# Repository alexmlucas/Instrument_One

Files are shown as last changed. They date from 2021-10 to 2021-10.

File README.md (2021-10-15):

# Instrument_One
A guitar-inspired accessible musical instrument

Instrument One was designed in collaboration with physically disabled musician Eoin Fitzpatrick, his father Peter and the Drake Music Project Northern Ireland. It is a novel, guitar-inspired accessible instrument that recreates the experience of selecting chords on a fretboard and strumming guitar strings. It is a novel instrument, tailored towards Eoin's unique requirements.

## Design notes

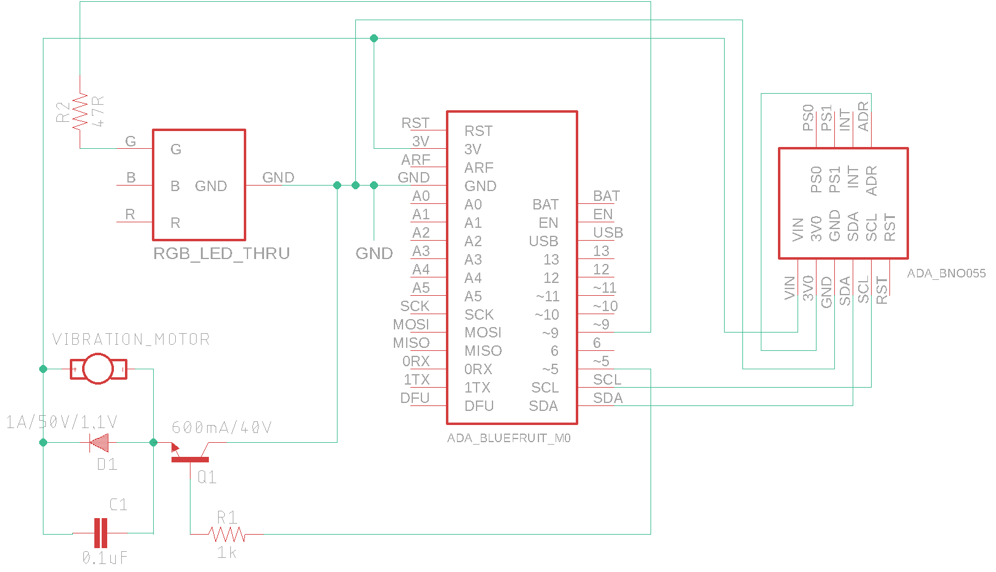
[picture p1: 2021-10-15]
electronics/wristband_schematic.png

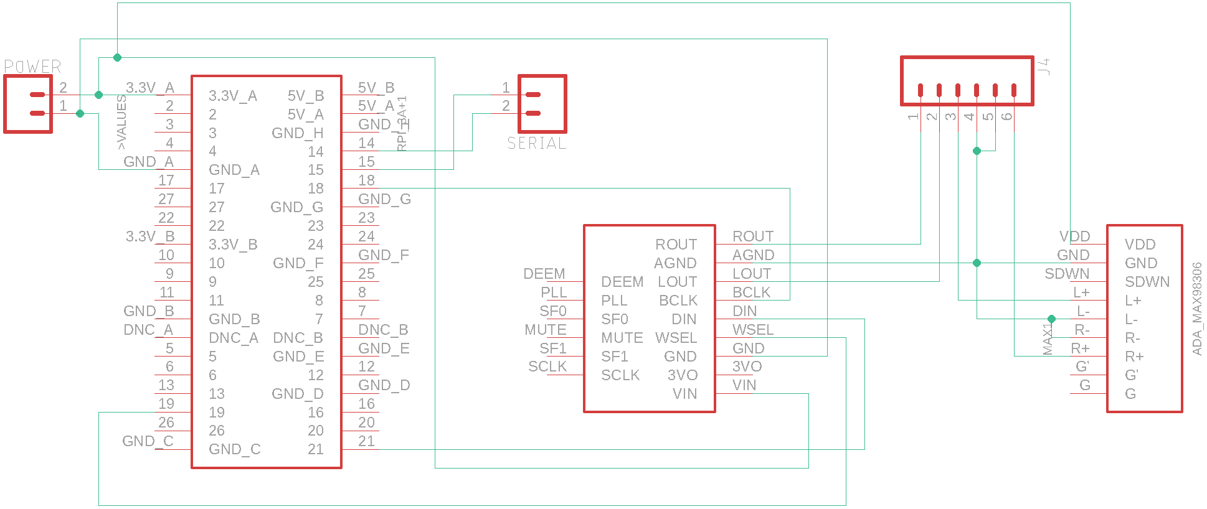
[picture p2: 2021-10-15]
electronics/audio_hat_schematic.png

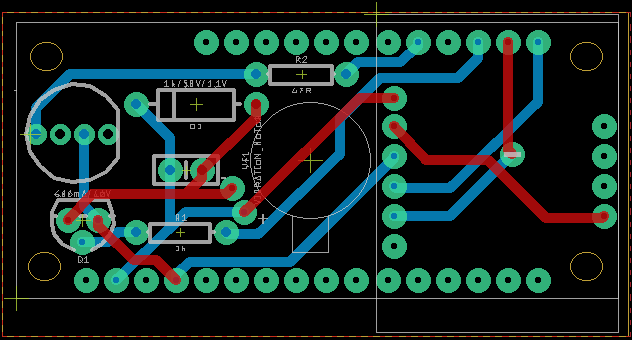
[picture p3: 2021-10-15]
electronics/wristband_board_layout.png

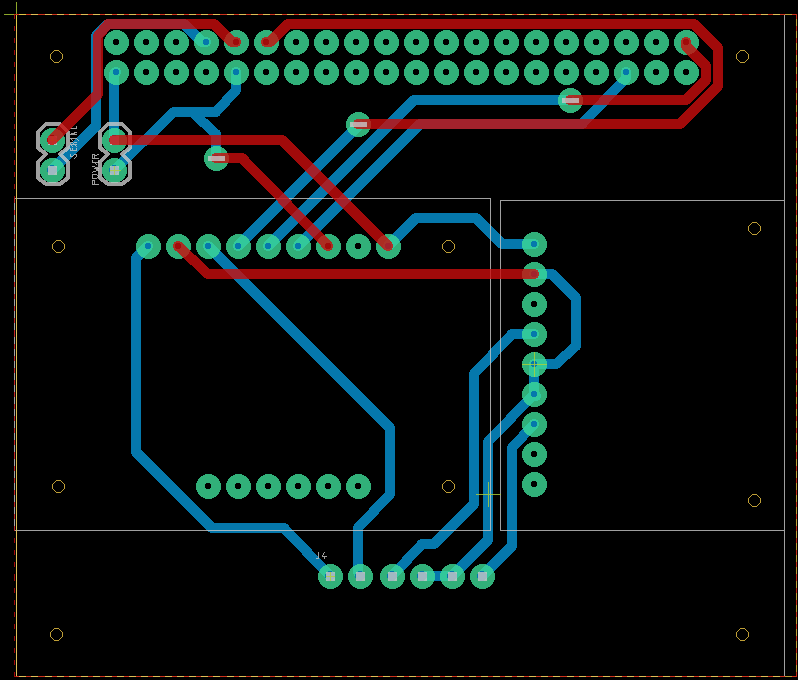
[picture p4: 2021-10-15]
electronics/audio_hat_board_layout.png

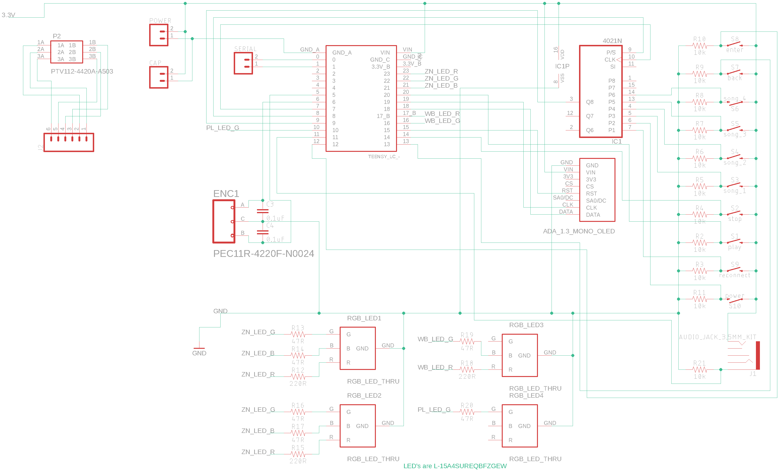
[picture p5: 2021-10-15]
electronics/control_board_schematic.png

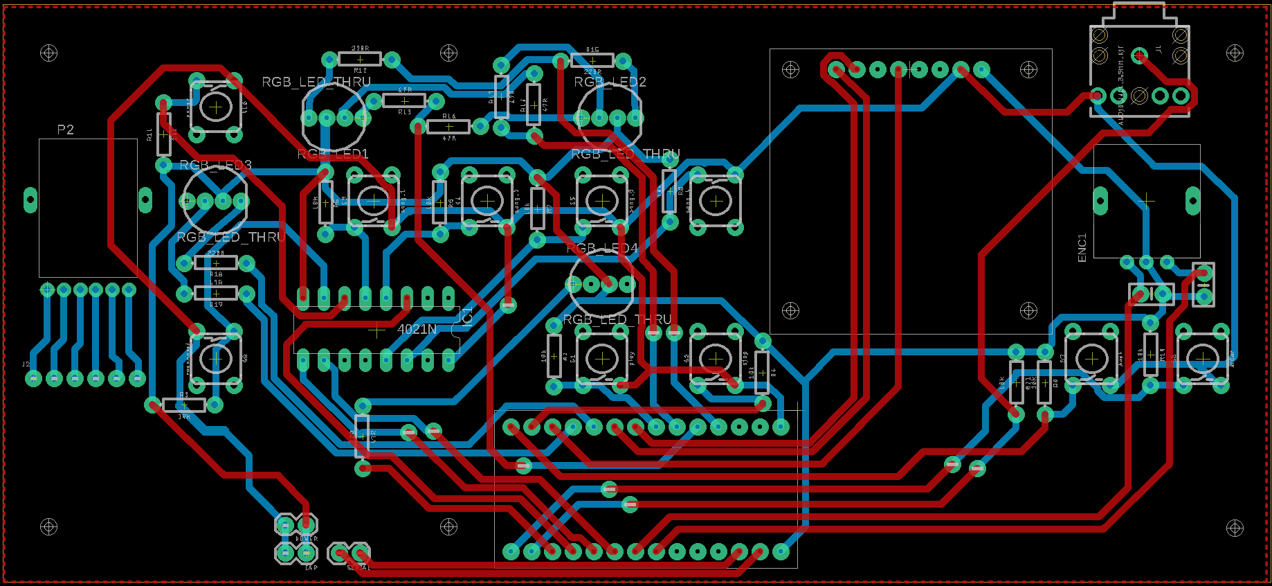
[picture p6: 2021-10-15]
electronics/control_board_layout.png

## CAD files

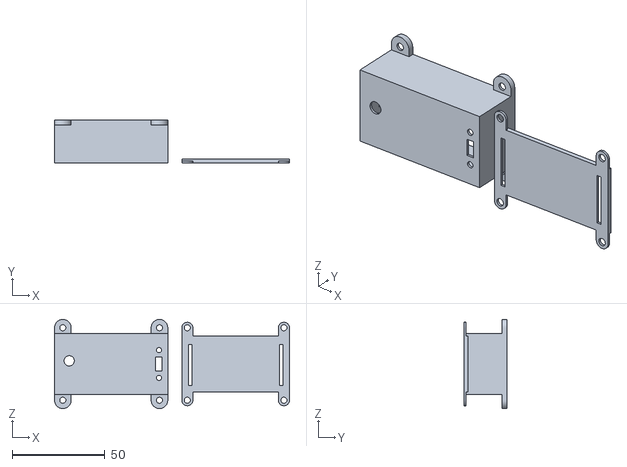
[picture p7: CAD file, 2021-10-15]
hardware/wristband_enclosure.stl
126.5 x 23.0 x 48.0

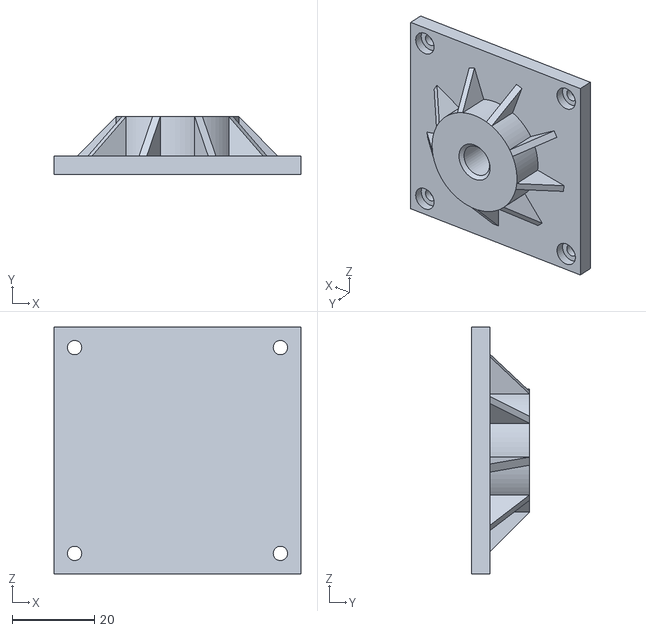
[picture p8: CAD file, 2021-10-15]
hardware/camera_mount.stl
60.0 x 14.0 x 60.0

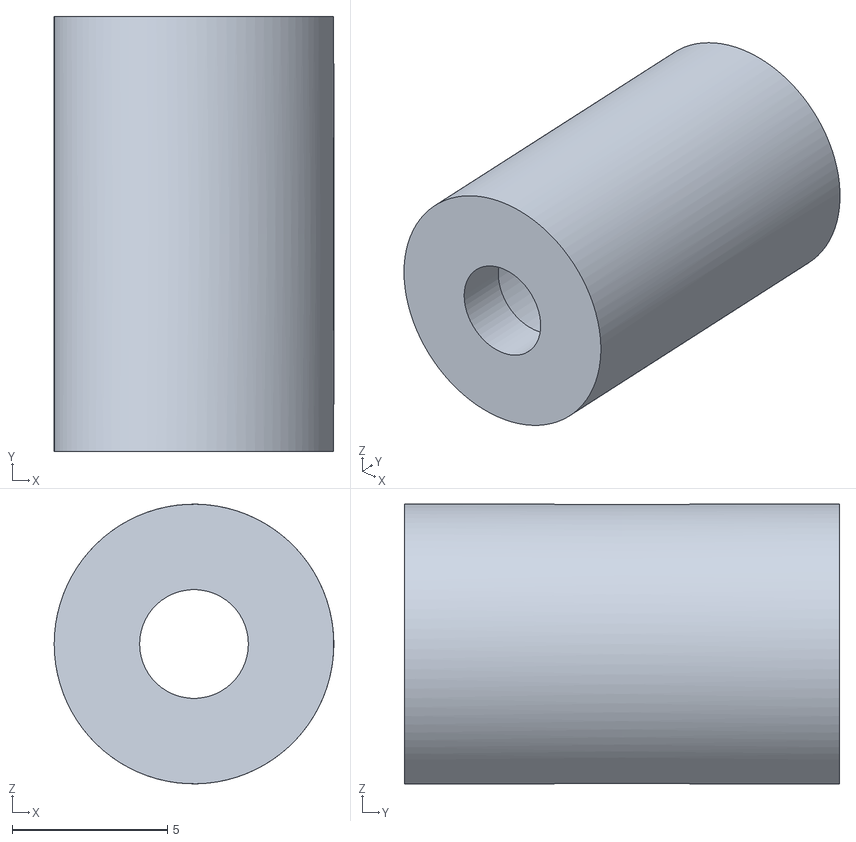
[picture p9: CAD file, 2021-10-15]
hardware/feet.stl
9.00 x 14.0 x 9.00

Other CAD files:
hardware/camera_mount.f3d
hardware/feet.f3d
hardware/wristband_enclosure.f3d

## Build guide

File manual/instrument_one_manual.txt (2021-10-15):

INSTRUMENT ONE MANUAL
=====================
Instrument One is a device that allows guitar sounds to be played via movement. It consists of three parts; an access switch, a wristband and a base unit.

Basic Operation
===============

Power On
--------
First, switch on the wristband. Next, ensure the USB memory stick is connected to the base unit. Switch on the base unit by connecting the USB power adapter. Once the base unit is booted, it will automatically attempt to connect wirelessly to the wristband; this process can sometimes take a few seconds.

Songs
-----
There are four songs to choose from. The guitar sound is configured differently for each song. Each song has a backing track loaded from the USB Memory stick when the base unit is powered on. Songs can be played using the Play/Pause and Stop buttons.

Playing
-------
Eoin will use his right arm to play the strings of the virtual guitar. The wristband will track arm movement; therefore, strap the wristband to Eoin’s right wrist. Ensure that the ‘RH Side’ sticker is indeed facing the right-hand side.

The access switch is used to change the scale. There are three scales for Eoin to choose from within each song. Each scale has a colour associated with it; Red, Green and Blue. Position the switch so that Eoin can press it using his left cheek.

Position the base unit so that the speakers are facing Eoin and that he can see the LEDs at the back of the unit clearly. The LEDs are used to indicate to Eoin which scale is currently selected.

Volume
------
The volume of the speakers is set using the ‘Speaker Volume’ dial. This dial has no effect on the ‘Audio Output’ socket. The volume of the ‘Audio Output’ socket is set using the Mix controls described overleaf.

Wristband
---------
The wristband has an internal battery that needs to be charged before use. Connect the USB power adapter and place the power switch in the On/Charge position to charge the battery.

If the wristband fails to connect or loses connection at any point, just press the ‘Reconnect’ button to attempt to reconnect.
Advanced Operation

Songs
-----
Songs are presets that store the following:
⦁	A backing track.
⦁	A guitar sound.
⦁	The scale and root note for each Zone.
⦁	The mix levels of the backing track and guitar.

Backing Tracks
--------------
The backing tracks used by each song are contained in a folder named ‘songs’ on the USB memory stick. The songs are 16 bit, 44.1 kHz Wav files labelled 1.wav through to 4.wav and correspond to each of the four songs.

To change a backing track, simply replace the corresponding Wav file on the USB memory stick. Once the USB Memory stick is reconnected to the base unit, the song will need to be reselected for these changes to take effect.

Guitar
------
There are three guitars; Classic Rock, Hard Rock and Acoustic, which can be selected via the ‘Guitar’ menu.

Zones
-----
‘Zone’ is the term used to describe the scales available to Eoin within a song. The Zones are coloured Red, Green and Blue. Each Zone has a scale and root note assigned to it, accessed via the Zone menu.

Mix
---
The level of the backing track and guitar of each song can be set within the Mix menu. The ‘Master’ parameter in the Mix menu controls the level of both the Audio Output and speakers and is a global parameter not stored with individual songs.

USB MIDI
--------
A class-compliant MIDI output is provided by the USB MIDI socket. The device will appear as ‘Teensy MIDI’ and transmits note data according to the selected Zone.

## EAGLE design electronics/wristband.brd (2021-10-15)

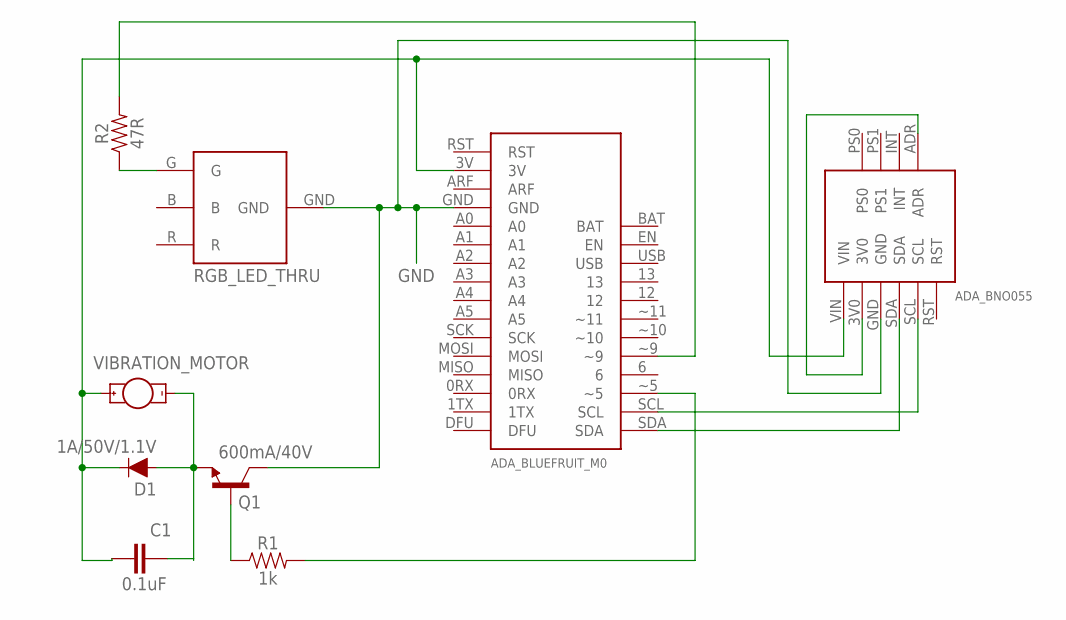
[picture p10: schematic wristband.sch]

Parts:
BF1: ADA_BLUEFRUIT_M0
BNO1: ADA_BNO055
C1: 0.1uF; CAP-PTH-SMALL-KIT
D1: 1A/50V/1.1V; DIODE-1N4001
Q1: 600mA/40V; TO-92
R1: 1k; AXIAL-0.3
R2: 47R; AXIAL-0.3
RGB_LED1: RGB_LED_THRU; RGB_LEB_RGB_2
U$1: VIBRATION_MOTOR

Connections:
GND: BF1.GND, BNO1.GND, Q1.1 (C), RGB_LED1.GND
unnamed: BF1.SDA, BNO1.SDA
unnamed: BF1.SCL, BNO1.SCL
unnamed: BF1.3V, BNO1.VIN, C1.1, D1.C, U$1.+
unnamed: BNO1.3V0, BNO1.ADR
unnamed: R2.P$1 (1), RGB_LED1.G
unnamed: BF1.~9, R2.P$2 (2)
unnamed: C1.2, D1.A, Q1.3 (E), U$1.-
unnamed: Q1.2 (B), R1.P$1 (1)
unnamed: BF1.~5, R1.P$2 (2)

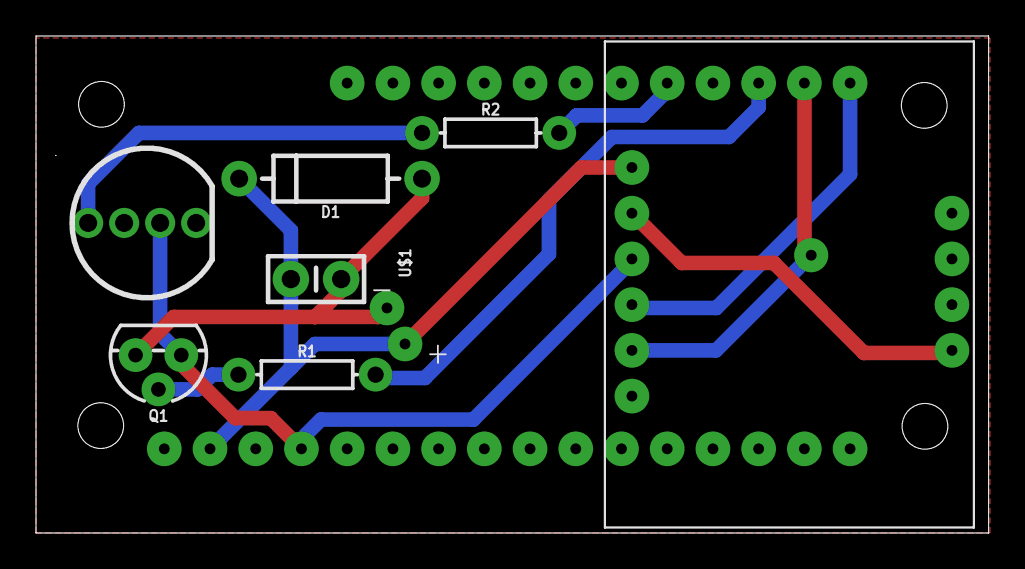
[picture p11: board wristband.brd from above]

Board: 2 copper layers, 52.9 x 27.6 mm, 9 parts (0 on the bottom side), 10 nets.

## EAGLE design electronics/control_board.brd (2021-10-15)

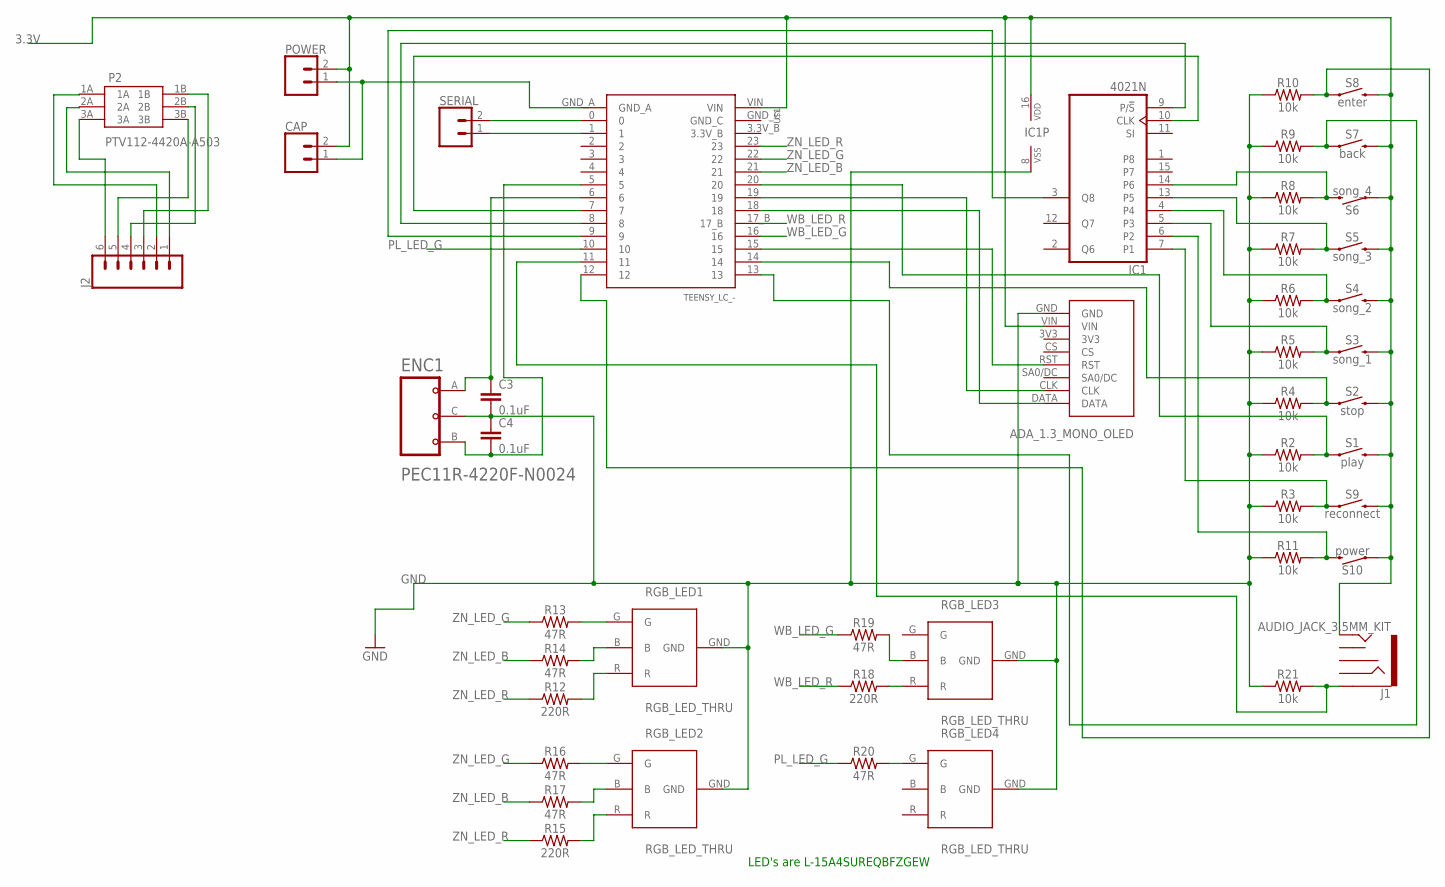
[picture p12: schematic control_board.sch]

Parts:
C3, C4: 0.1uF; CAP-PTH-SMALL-KIT
CAP: CONN_02; 1X02
ENC1: PEC11R-4220F-N0024
IC1: 4021N; DIL16
J1: AUDIO_JACK_3.5MM_KIT; AUDIO-JACK-KIT
J2: CONN_06NO_SILK_NO_POP; 1X06_NO_SILK
OLED1: ADA_1.3_MONO_OLED
P2: PTV112-4420A-A503; PTV122-4420A-A503
POWER: CONN_02; 1X02
R2, R3, R4, R5, R6, R7, R8, R9, R10, R11, R21: 10k; AXIAL-0.3
R12, R15, R18: 220R; AXIAL-0.3
R13, R14, R16, R17, R19, R20: 47R; AXIAL-0.3
RGB_LED1, RGB_LED2, RGB_LED3, RGB_LED4: RGB_LED_THRU; RGB_LEB_RGB_2
S1: play; TACTILE_SWITCH_PTH_6.0MM
S2: stop; TACTILE_SWITCH_PTH_6.0MM
S3: song_1; TACTILE_SWITCH_PTH_6.0MM
S4: song_2; TACTILE_SWITCH_PTH_6.0MM
S5: song_3; TACTILE_SWITCH_PTH_6.0MM
S6: song_4; TACTILE_SWITCH_PTH_6.0MM
S7: back; TACTILE_SWITCH_PTH_6.0MM
S8: enter; TACTILE_SWITCH_PTH_6.0MM
S9: reconnect; TACTILE_SWITCH_PTH_6.0MM
S10: power; TACTILE_SWITCH_PTH_6.0MM
SERIAL: CONN_02; 1X02
U$1: TEENSY_LC_-

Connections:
3.3V: CAP.2, IC1.16 (VDD), J1.TIP, OLED1.VIN, POWER.2, S1.3 (2), S2.3 (2), S3.3 (2), S4.3 (2), S5.3 (2), S6.1, S7.3 (2), S8.3 (2), S9.3 (2), S10.1, U$1.VIN
GND: C3.2, C4.1, CAP.1, ENC1.C (COMMON), IC1.8 (VSS), OLED1.GND, POWER.1, R2.P$1 (1), R3.P$1 (1), R4.P$1 (1), R5.P$1 (1), R6.P$1 (1), R7.P$1 (1), R8.P$1 (1), R9.P$1 (1), R10.P$1 (1), R11.P$1 (1), R21.P$1 (1), RGB_LED1.GND, RGB_LED2.GND, RGB_LED3.GND, RGB_LED4.GND, U$1.GND_A
unnamed: IC1.3 (Q8), U$1.9
unnamed: R13.P$2 (2), RGB_LED1.G
unnamed: R14.P$2 (2), RGB_LED1.B
unnamed: IC1.10 (CLK), U$1.7
unnamed: R12.P$2 (2), RGB_LED1.R
unnamed: R16.P$2 (2), RGB_LED2.G
unnamed: R17.P$2 (2), RGB_LED2.B
unnamed: IC1.9 (P/!S), U$1.8
unnamed: OLED1.DATA, U$1.18
unnamed: R4.P$2 (2), S2.1, U$1.14
unnamed: R9.P$2 (2), S7.1, U$1.13
unnamed: IC1.5 (P3), R5.P$2 (2), S3.1
unnamed: IC1.4, R6.P$2 (2), S4.1
unnamed: J1.SLEEVE, R21.P$2 (2), U$1.11
unnamed: IC1.13 (P5), R7.P$2 (2), S5.1
unnamed: IC1.14 (P6), R8.P$2 (2), S6.3 (2)
unnamed: SERIAL.1, U$1.1
unnamed: R10.P$2 (2), S8.1, U$1.12
unnamed: C3.1, ENC1.A (CHANNEL_A), U$1.6
unnamed: C4.2, ENC1.B (COMMON_B), U$1.5
unnamed: IC1.7 (P1), R3.P$2 (2), S9.1
unnamed: IC1.6 (P2), R11.P$2 (2), S10.3 (2)
unnamed: R15.P$2 (2), RGB_LED2.R
unnamed: R19.P$2 (2), RGB_LED3.B
unnamed: R18.P$2 (2), RGB_LED3.R
unnamed: R20.P$2 (2), RGB_LED4.G
unnamed: R2.P$2 (2), S1.1, U$1.20
unnamed: SERIAL.2, U$1.0
unnamed: J2.2, P2.1A
unnamed: OLED1.CLK, U$1.19
unnamed: OLED1.RST, U$1.15
unnamed: J2.1, P2.2A
unnamed: J2.6, P2.3A
unnamed: J2.4, P2.2B
unnamed: J2.5, P2.3B
unnamed: J2.3, P2.1B
PL_LED_G: R20.P$1 (1), U$1.10
WB_LED_G: R19.P$1 (1), U$1.16
WB_LED_R: R18.P$1 (1), U$1.17_B
ZN_LED_B: R14.P$1 (1), R17.P$1 (1), U$1.21
ZN_LED_G: R13.P$1 (1), R16.P$1 (1), U$1.22
ZN_LED_R: R12.P$1 (1), R15.P$1 (1), U$1.23

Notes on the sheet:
LED's are L-15A4SUREQBFZGEW

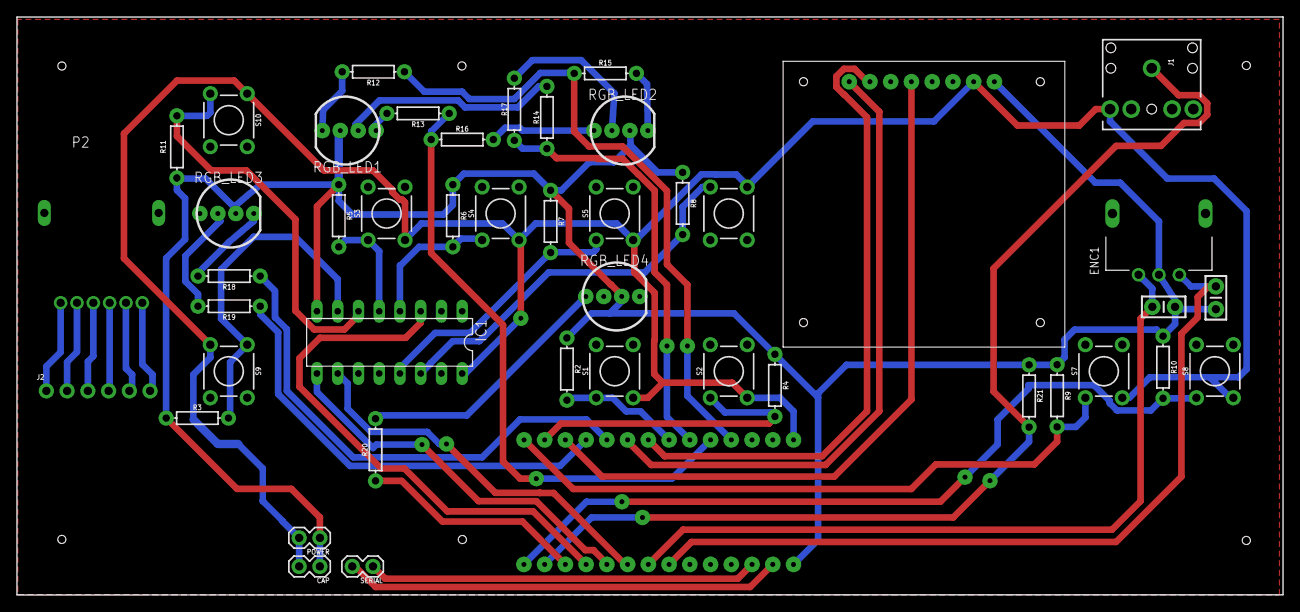
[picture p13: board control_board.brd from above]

Board: 2 copper layers, 155.0 x 70.8 mm, 46 parts (1 on the bottom side), 44 nets.

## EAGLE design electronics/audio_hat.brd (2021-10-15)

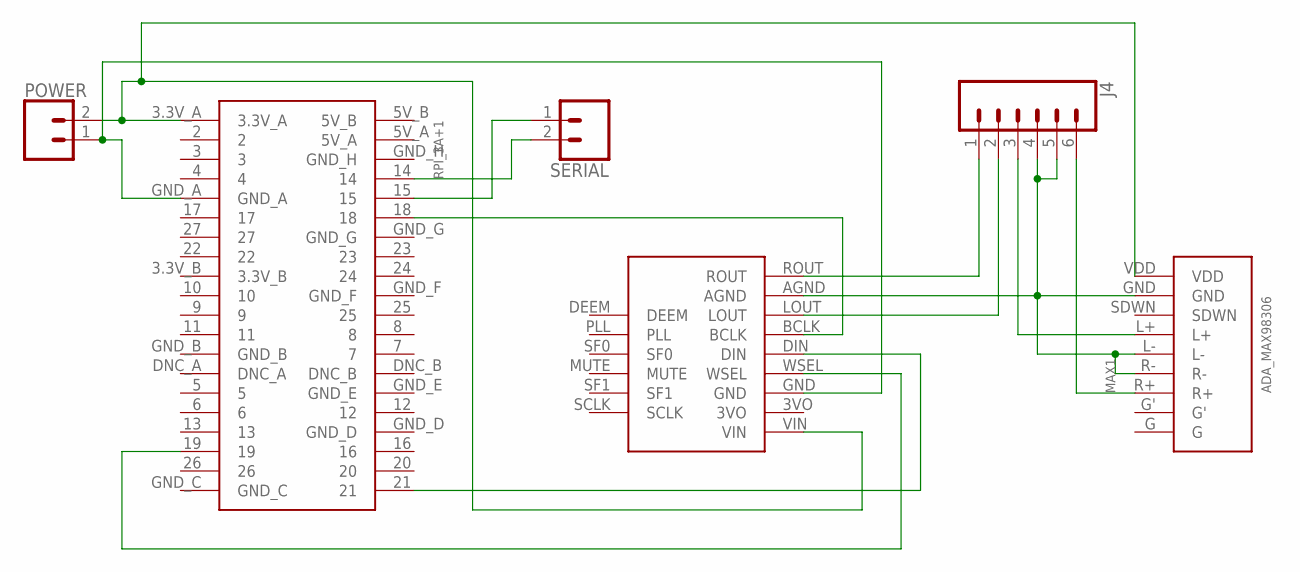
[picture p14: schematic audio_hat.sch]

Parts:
J4: CONN_06NO_SILK_NO_POP; 1X06_NO_SILK
MAX1: ADA_MAX98306
POWER: CONN_02; 1X02
RPI_3A+1: RPI_3A+
SERIAL: CONN_02; 1X02
UDA1: ADA_UDA1334

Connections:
unnamed: RPI_3A+1.19, UDA1.WSEL
unnamed: POWER.1, RPI_3A+1.GND_A, UDA1.GND
unnamed: MAX1.VDD, POWER.2, RPI_3A+1.3.3V_A, UDA1.VIN
unnamed: RPI_3A+1.21, UDA1.DIN
unnamed: J4.1, UDA1.ROUT
unnamed: J4.2, UDA1.LOUT
unnamed: J4.4, J4.5, MAX1.GND, MAX1.L-, MAX1.R-, UDA1.AGND
unnamed: J4.3, MAX1.L+
unnamed: RPI_3A+1.14, SERIAL.2
unnamed: J4.6, MAX1.R+
unnamed: RPI_3A+1.15, SERIAL.1
unnamed: RPI_3A+1.18, UDA1.BCLK

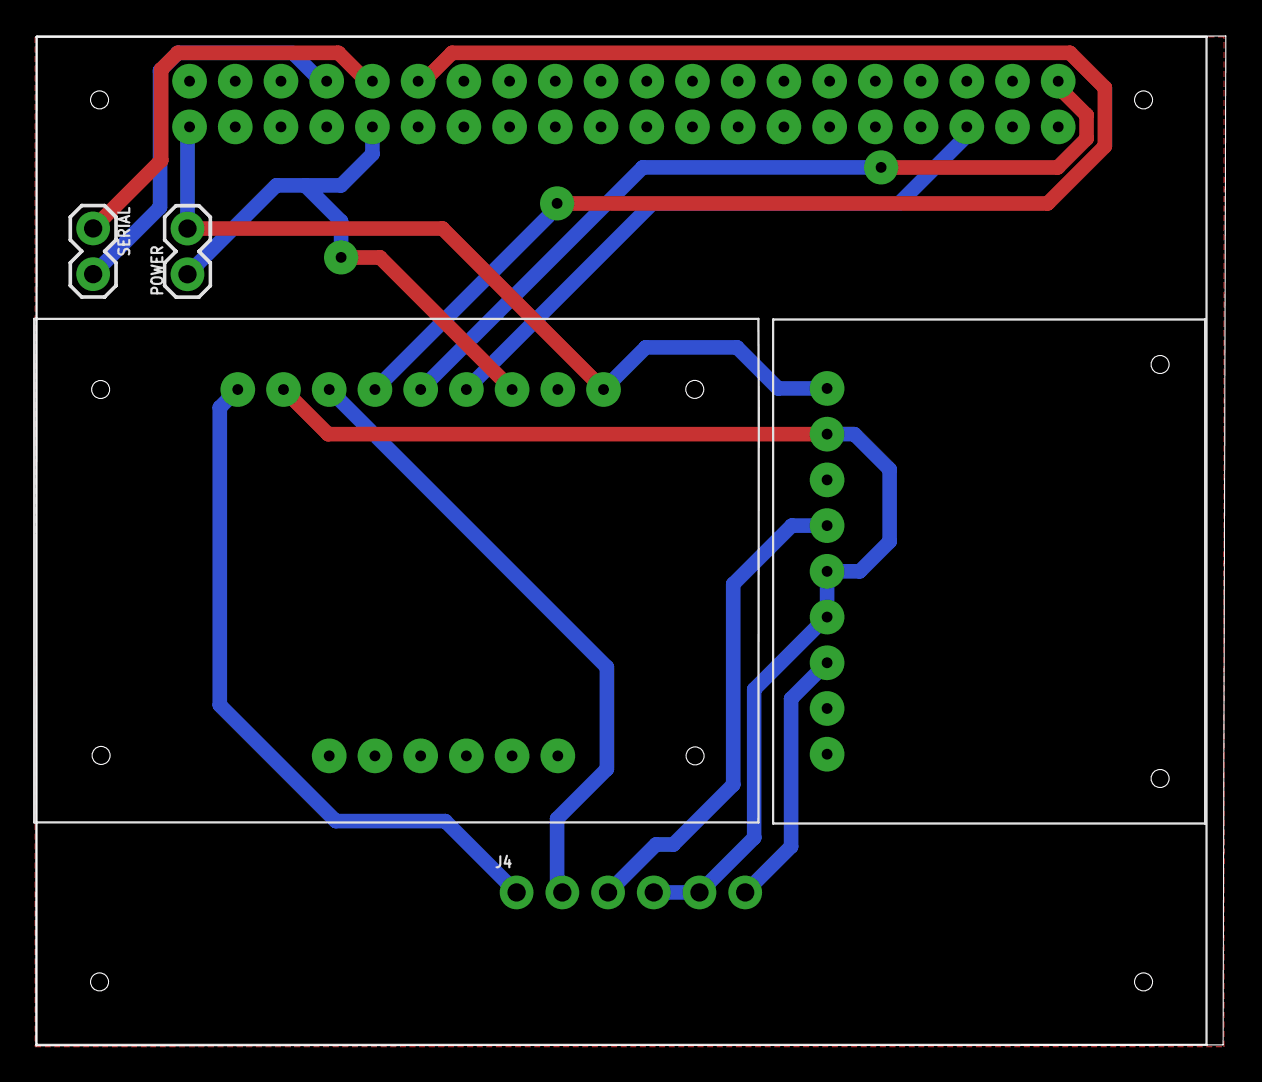
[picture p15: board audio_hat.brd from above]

Board: 2 copper layers, 66.1 x 56.1 mm, 6 parts (0 on the bottom side), 12 nets.

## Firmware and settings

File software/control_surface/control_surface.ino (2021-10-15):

// Display includes
#include <SPI.h>
#include <Wire.h>
#include <Adafruit_GFX.h>
#include <Adafruit_SSD1306.h>

// Control includes
#include "Control_Button.h"
#include "Shift_Register_Control_Button.h"
#include "Shift_Register_Menu_Button.h"
#include "Simple_Encoder.h"
#include "Single_Led.h"
#include "Rg_Led.h"
#include "Rgb_Led.h"

// Menu includes
#include "Menu_Page.h"
#include "Main_Page.h"
#include "List_Page.h"
#include "Selection_Page.h"
#include "Value_Page.h"
#include "Splash_Page.h"
#include "Menu_Controller.h"
#include "Parameter_Container.h"

#define OLED_RESET 15

// Create an instance of the display
Adafruit_SSD1306 display(OLED_RESET);

// Define the debounce time in milliseconds
#define DEBOUNCE_TIME 50

// Define the USB MIDI Note Velocity
#define NOTE_VELOCITY 100

// Define the encoder pins
#define ENCODER_PIN_A 5
#define ENCODER_PIN_B 6

// Define the button/switch pins
#define ACCESS_SWT_PIN 11
#define PLAY_BTN_PIN 20
#define STOP_BTN_PIN 14
#define BACK_BTN_PIN 13
#define ENTER_BTN_PIN 12

// Define button bits
#define RECONNECT_BTN_BIT 0
#define POWER_BTN_BIT 1
#define SONG_1_BTN_BIT 2
#define SONG_2_BTN_BIT 3
#define SONG_3_BTN_BIT 4
#define SONG_4_BTN_BIT 5

// Define the shift register pins.
#define SHIFT_REG_LATCH 8
#define SHIFT_REG_DATA 9
#define SHIFT_REG_CLOCK 7

// Define LED pins
#define ZN_LED_R A9
#define ZN_LED_G A8
#define ZN_LED_B A7
#define WB_LED_R A3
#define WB_LED_G A2
#define PL_LED_G 10

// Define play button states
#define PLAYING 0
#define PAUSED 1
#define STOPPED 2

// Define the min & max cursor values
#define MIN_CURSOR_VALUE 0
#define MAX_CURSOR_VALUE 2

// Define characters to be sent as serial strings.
const char RECONNECT_CHAR PROGMEM = 'a'; 
const char POWER_CHAR PROGMEM = 'b';
const char ACCESS_SWT_CHAR PROGMEM = 'c';
const char PLAY_CHAR PROGMEM = 'd';
const char STOP_CHAR PROGMEM = 'e';
const char SONG_1_CHAR PROGMEM = 'f';
const char SONG_2_CHAR PROGMEM = 'g';
const char SONG_3_CHAR PROGMEM = 'h';
const char SONG_4_CHAR PROGMEM = 'i';
const char BACK_CHAR PROGMEM = 'j';
const char ENTER_CHAR PROGMEM = 'k';

const static char song[] PROGMEM = "Song";
const static char guitar[] PROGMEM = "Guitar";
const char backing[] PROGMEM = "Backing";
const char master[] PROGMEM = "Master";
const static char zone[] PROGMEM = "Zone";
const static char mix_levels[] PROGMEM = "Mix Levels";
const char red_zone[] PROGMEM = "Red Zone";
const char green_zone[] PROGMEM = "Green Zone";
const char blue_zone[] PROGMEM = "Blue Zone";

const static char classic_rock[] PROGMEM = "Classic Rock";
const static char hard_rock[] PROGMEM = "Hard Rock";
const static char acoustic[] PROGMEM = "Acoustic";
const char scale[] PROGMEM = "Scale";
const char red_scale[] PROGMEM = "Red Scale";
const char green_scale[] PROGMEM = "Green Scale";
const char blue_scale[] PROGMEM = "Blue Scale";
const char root[] PROGMEM = "Root";
const char red_root[] PROGMEM = "Red Root";
const char green_root[] PROGMEM = "Green Root";
const char blue_root[] PROGMEM = "Blue Root";
const static char connecting[] PROGMEM = "Connecting";
const static char to_wristband[] PROGMEM = "to wristband,";
const static char please_wait[] PROGMEM = "please wait...";
const char sorry[] PROGMEM = "Sorry, I couldn't";
const char not_connect[] PROGMEM = "connect to";
const char the_wristband[] PROGMEM = "the wristband.";
const char not_load_song[] PROGMEM = "load song. Connect";
const char check_memory[] PROGMEM = "USB stick & reboot.";


//const char scale_param[] PROGMEM = "Major, Minor, Blues, Pent. Major, Pent. Minor, Major Chord, Minor Chord";
//const char root_param[] PROGMEM = "A, A#, B, C, C#, D, D#, E, F, F#, G, G#";

const char test_array[] PROGMEM = "test";
//const char flash_test PROGMEM = 'f';

// An array of constant pointers to constant chars?
const static char *const main_menu_txt[] PROGMEM = {song, guitar, zone, mix_levels};
const char *const guitar_menu_txt[] PROGMEM = {guitar, classic_rock, hard_rock, acoustic};
const char *const zone_menu_txt[] PROGMEM = {zone, red_zone, green_zone, blue_zone};
const char *const red_zone_menu_txt[] PROGMEM = {red_zone, scale, root};
const char *const green_zone_menu_txt[] PROGMEM = {green_zone, scale, root};
const char *const blue_zone_menu_txt[] PROGMEM = {blue_zone, scale, root};
const char *const red_scale_menu_txt[] PROGMEM = {red_scale};
const char *const green_scale_menu_txt[] PROGMEM = {green_scale};
const char *const blue_scale_menu_txt[] PROGMEM = {blue_scale};
const char *const red_root_menu_txt[] PROGMEM = {red_root};
const char *const green_root_menu_txt[] PROGMEM = {green_root};
const char *const blue_root_menu_txt[] PROGMEM = {blue_root};

const char *const mix_levels_menu_txt[] PROGMEM = {mix_levels, guitar, backing, master};
const char *const guitar_level_menu_txt[] PROGMEM = {guitar}; 
const char *const backing_level_menu_txt[] PROGMEM = {backing}; 
const char *const master_level_menu_txt[] PROGMEM = {master};

const static char *const reconnect_menu_txt[] PROGMEM = {connecting, to_wristband, please_wait};
const char *const connection_fail_menu_txt[] PROGMEM = {sorry, not_connect, the_wristband};
const char *const song_fail_menu_txt[] PROGMEM = {sorry, not_load_song, check_memory};

const char* const mix_levels_param_txt[] PROGMEM = {"0", "0.1", "0.2", "0.3", "0.4", "0.5", "0.6", "0.7", "0.8", "0.9", "1"};
const char* const scales_param_txt[] PROGMEM = {"Pent. Major", "Pent. Minor", "Blues", "Major Chord", "Minor Chord"};
const char* const root_param_txt[] PROGMEM = {"E", "F", "F#", "G", "G#", "A", "A#", "B", "C", "C#", "D", "D#"};

// Define a variable to hold the data from the shift register
byte shift_reg_byte = 0;

// Create Simple_Encoder instance.
Simple_Encoder selection_encoder;

// A pointer to an array of constant pointers to constant chars.
const char *const *menu_text_pointer;

// Byte for storing incoming serial data.
char incoming_byte_1;
char incoming_byte_2;
char incoming_byte_3;

// String representing the current menu location.
char current_menu_location[] = {""};

// Buffer for reading menu text.
char string_buffer[30];

// Read and monitior encoder position.
int current_encoder_position, last_encoder_position;

Menu_Controller menu_controller(MIN_CURSOR_VALUE, MAX_CURSOR_VALUE);      // Create an instance of Menu_Controller.
Parameter_Container parameter_container;                                  // Create an instance of Parameter_Container.
Parameter_Container *p_parameter_container;

// *** Initialise Menu_Page(s) ***
Main_Page main_menu(&menu_controller, &parameter_container);
Selection_Page guitar_menu(&menu_controller, &parameter_container);
List_Page zone_menu(&menu_controller, &parameter_container);
List_Page mix_levels_menu(&menu_controller, &parameter_container);
List_Page red_zone_menu(&menu_controller, &parameter_container);
List_Page green_zone_menu(&menu_controller, &parameter_container);
List_Page blue_zone_menu(&menu_controller, &parameter_container);
Value_Page red_scale_menu(&menu_controller, &parameter_container);
Value_Page red_root_menu(&menu_controller, &parameter_container);
Value_Page green_scale_menu(&menu_controller, &parameter_container);
Value_Page green_root_menu( &menu_controller, &parameter_container);
Value_Page blue_scale_menu(&menu_controller, &parameter_container);
Value_Page blue_root_menu(&menu_controller, &parameter_container);
Value_Page guitar_level_menu(&menu_controller, &parameter_container);
Value_Page backing_level_menu(&menu_controller, &parameter_container);
Value_Page master_level_menu(&menu_controller, &parameter_container);
Splash_Page reconnect_menu(&menu_controller, &parameter_container);
Splash_Page connection_fail_menu(&menu_controller, &parameter_container);
Splash_Page song_fail_menu(&menu_controller, &parameter_container);

// *** Initialise Pointers to Sub Menu_Page(s) ***  
Menu_Page *p_main_sub_menus[] = {&guitar_menu, &zone_menu, &mix_levels_menu};                        
Menu_Page *p_zone_sub_menus[] = {&red_zone_menu, &green_zone_menu, &blue_zone_menu};
Menu_Page *p_red_zone_sub_menus[] = {&red_scale_menu, &red_root_menu};
Menu_Page *p_green_zone_sub_menus[] = {&green_scale_menu, &green_root_menu};
Menu_Page *p_blue_zone_sub_menus[] = {&blue_scale_menu, &blue_root_menu};    
Menu_Page *p_mix_levels_sub_menus[] = {&guitar_level_menu, &backing_level_menu, &master_level_menu};

Menu_Page *p_current_menu_page;                                           // Create a pointer to the currently selected menu page.
Menu_Page *p_previous_menu_page;                                          // Create a pointer to the previously selected menu page.
Menu_Page *p_wristband_return_page;                                       // Creat a pointer to the page to retrn to after wristabnd conneciton messages have been displayed.

// *** Create Simple_Button instances ***
Control_Button access_switch(ACCESS_SWT_PIN, DEBOUNCE_TIME, &menu_controller, &parameter_container, &parameter_container.m_zone, 0);
Control_Button play_button(PLAY_BTN_PIN, DEBOUNCE_TIME, &menu_controller, &parameter_container, &parameter_container.m_play, 1);
Control_Button stop_button(STOP_BTN_PIN, DEBOUNCE_TIME, &menu_controller, &parameter_container, &parameter_container.m_play, 0);
Menu_Button back_button(BACK_BTN_PIN, DEBOUNCE_TIME, &menu_controller);
Menu_Button enter_button(ENTER_BTN_PIN, DEBOUNCE_TIME, &menu_controller);

// *** Create Shift_Register_Button instances ***
Shift_Register_Control_Button reconnect_button(RECONNECT_BTN_BIT, DEBOUNCE_TIME, &menu_controller, &parameter_container, &parameter_container.m_reconnect, 0);
Shift_Register_Control_Button power_button(POWER_BTN_BIT, DEBOUNCE_TIME, &menu_controller, &parameter_container, &parameter_container.m_power, 0);
Shift_Register_Control_Button song_1_button(SONG_1_BTN_BIT, DEBOUNCE_TIME, &menu_controller, &parameter_container, &parameter_container.m_song, 0);
Shift_Register_Control_Button song_2_button(SONG_2_BTN_BIT, DEBOUNCE_TIME, &menu_controller, &parameter_container, &parameter_container.m_song, 1);
Shift_Register_Control_Button song_3_button(SONG_3_BTN_BIT, DEBOUNCE_TIME, &menu_controller, &parameter_container, &parameter_container.m_song, 2);
Shift_Register_Control_Button song_4_button(SONG_4_BTN_BIT, DEBOUNCE_TIME, &menu_controller, &parameter_container, &parameter_container.m_song, 3);

// *** Create Led instances ***
int zone_led_pins[] = {ZN_LED_R, ZN_LED_G, ZN_LED_B};
int wristband_led_pins[] = {WB_LED_R, WB_LED_G};

int RG_RED[] = {255, 0};
int RG_GREEN[] = {0, 255};
int RG_OFF[] = {0, 0};

int RGB_RED[] = {255, 0, 0};
int RGB_GREEN[] = {0, 255, 0};
int RGB_BLUE[] = {0, 0, 255};
int RGB_OFF[] = {0, 0, 0};

int *p_rgb_red = RGB_RED; 
int *p_rgb_blue = RGB_BLUE; 
bool FLASH_ALL[] = {true, true, true};

Single_Led play_led;
Rg_Led wristband_leds;
Rgb_Led zone_leds;

// Timer variables for deactivating Splash Pages
int time_splash_loaded_ms;
int SPLASH_DISPLAY_TIME = 3000;
int current_time_ms;
bool splash_page_loaded;

// Variable for tracking whether or not a song is loaded.
bool song_loaded = false;
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
void loop() {
  
  if(splash_page_loaded){
    current_time_ms = millis();

    if((current_time_ms - time_splash_loaded_ms) > SPLASH_DISPLAY_TIME){
      // This method will also set the redraw display flag.
      menu_controller.set_currently_selected_menu(p_wristband_return_page);
      splash_page_loaded = false;
    }
  }
  
  if(menu_controller.get_redraw_display_flag() == true){
    // Assign pointer to the currently selected menu.
    p_current_menu_page = (Menu_Page*)menu_controller.get_currently_selected_menu();
    
    if(p_current_menu_page != p_previous_menu_page){
      menu_controller.set_cursor_position(0);             // The menu page has changed so reset the cursor position. 
    }
    
    p_current_menu_page->draw(display);
    menu_controller.set_redraw_display_flag(false);

    p_previous_menu_page = p_current_menu_page;           // Update the previous menu page.
  }
  
  // Set the latch pin to 1 to collect parallel data.
  digitalWrite(SHIFT_REG_LATCH, 1);
  delayMicroseconds(1);
  // Set the latch pin to to 0 to transmit data serially.
  digitalWrite(SHIFT_REG_LATCH, 0);
  // Collect the register as a byte.
  shift_reg_byte = shift_in(SHIFT_REG_DATA, SHIFT_REG_CLOCK);

  // Process the shift register buttons
  reconnect_button.check_button_pressed(shift_reg_byte);
  power_button.check_button_pressed(shift_reg_byte);
  song_1_button.check_button_pressed(shift_reg_byte);
  song_2_button.check_button_pressed(shift_reg_byte);
  song_3_button.check_button_pressed(shift_reg_byte);
  song_4_button.check_button_pressed(shift_reg_byte);
  
  // Process the buttons connected directly to the microcontroller
  access_switch.check_button_pressed();
  play_button.check_button_pressed();
  stop_button.check_button_pressed();
  back_button.check_button_pressed();
  enter_button.check_button_pressed();
  
  // Process the leds that need to flash.
  play_led.update_flashing();
  wristband_leds.update_flashing();
 
  if(Serial1.available() > 0){              // If serial data is available...
    serial_parser();                        // ...call the parser.
  }

  // Get the current encoder position
  current_encoder_position = selection_encoder.track_position();

  // Has the value changed?
  if(current_encoder_position != last_encoder_position){
    // Print the value.
    Serial1.println(current_encoder_position);
    // Update the last known value.
    last_encoder_position = current_encoder_position;
  }
}

byte shift_in(int incoming_data_pin, int incoming_clock_pin){
  int i;
  int temp = 0;
  //int pin_state;
  byte data_in = 0;

  // Set the clock pin to high in preparation for
  // reading the first value.
  digitalWrite(incoming_clock_pin, 1);

  for(i = 7; i >= 0; i--){
    // The data pin changes value to the next pin of the
    // shift register on every transition from HIGH to LOW
    digitalWrite(incoming_clock_pin, 0);
    delayMicroseconds(0.2);
    temp = digitalRead(incoming_data_pin);
    // If the temp value is HIGH then...
    if(temp){
      // ...set the corresponding bit to 1.
      // The OR operation allows us to maintain the state of the other bits.
      data_in = data_in | (1 << i);
    }
    // Set the clock pin to high in preparation for
    // reading the next value.
    digitalWrite(incoming_clock_pin, 1);
  }
  return data_in;
}

void print_bits(byte incoming_byte){
  for(int i = 7; i >= 0; i--){
    Serial1.print(bitRead(incoming_byte,i));
  }
  Serial1.println();
}

void enter_pressed(Menu_Controller* p_menu_controller){                                // Function expects a pointer to a Menu_Controller.
  Menu_Page *m_menu = (Menu_Page*)p_menu_controller->m_currently_selected_menu;        // Create local pointer to the currently selected Menu_Page, via the Menu_Controller pointer.
  
  if(m_menu->m_enter_enabled){                                                         // if the currently selected menu has an on_enter() function...
    m_menu->on_enter();                                                                // ... call it.
  }                                                                   
}

void back_pressed(Menu_Controller* p_menu_controller){                                 // Function expects a pointer to a Menu_Controller.
  Menu_Page *m_menu = (Menu_Page*)p_menu_controller->m_currently_selected_menu;        // Create local pointer to the currently selected Menu_Page, via the Menu_Controller pointer.
  
  if(m_menu->m_back_enabled){                                                          // if the currently selected menu has an on_enter() function...
    m_menu->on_back();                                                                 // ... call it.
  }                                                      
}

void play_pressed(Single_Led *led, Parameter_Container *parameter_container, Parameter *parameter_struct, int parameter_value){
  // check to see if song is loaded before acting on play button events
  if(parameter_container->m_song_loaded.value == 1){
    switch(parameter_struct->value){
      case 0:
        parameter_container->set_and_send_parameter(parameter_struct, 1);         // Playback is currently stopped, so start it.
        led->set_on(true);                                                        // Update the led
        break;
      case 1:
        parameter_container->set_and_send_parameter(parameter_struct, 2);         // Song is playing already, so pause it.
        led->set_flashing(true);                                                  // Update the led
        break;
      case 2:
        parameter_container->set_and_send_parameter(parameter_struct, 1);         // Song is paused, so commence playback.
        led->set_on(true);                                                        // Update the led
        break;
    }
  }
}

void stop_pressed(Single_Led *led, Parameter_Container *parameter_container, Parameter *parameter_struct, int parameter_value){
  // check to see if song is loaded before acting on play button events
  if(parameter_container->m_song_loaded.value == 1){
    if(parameter_struct->value){
      parameter_container->set_and_send_parameter(parameter_struct, 0);          // Currently playing the song, so stop it.
      led->set_on(false);                                               
    }
  }
}

void song_pressed(Single_Led *led, Parameter_Container *parameter_container, Parameter *parameter_struct, int parameter_value){
  led->set_on(false);                                                                       // switch off the LED, which in this case is the play LED.
  parameter_container->set_and_send_parameter(&parameter_container->m_play, 0);             // set the play state to off.
  parameter_container->set_and_send_parameter(parameter_struct, parameter_value);           // update the currently selected song
}

void access_switch_pressed(Single_Led *led, Parameter_Container *parameter_container, Parameter *parameter_struct, int parameter_value){
  Rgb_Led *rgb_led = (Rgb_Led*)led;        // Create local pointer to the currently selected Menu_Page, via the Menu_Controller pointer.

  switch(parameter_struct->value){
    case 0:
      parameter_container->set_and_send_parameter(parameter_struct, 1);         // Increment parameter value
      rgb_led->set_colour(RGB_GREEN);                                           // Update the led
      break;
    case 1:
      parameter_container->set_and_send_parameter(parameter_struct, 2);         // Increment parameter value
      rgb_led->set_colour(RGB_BLUE);                                            // Update the led
      break;
    case 2:
      parameter_container->set_and_send_parameter(parameter_struct, 0);         // Reset parameter value to 0
      rgb_led->set_colour(RGB_RED);                                             // Update the led
      break;
  }
}
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

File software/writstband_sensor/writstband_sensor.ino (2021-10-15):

#include <Adafruit_BLE.h>
#include <Adafruit_BluefruitLE_UART.h>
#include <Adafruit_BluefruitLE_SPI.h>
#include "Adafruit_BLEGatt.h"
#include "BluefruitConfig.h"

#if SOFTWARE_SERIAL_AVAILABLE
  #include <SoftwareSerial.h>
#endif

#include <Wire.h>
#include <Adafruit_Sensor.h>
#include <Adafruit_BNO055.h>
#include <utility/imumaths.h>
  
Adafruit_BNO055 bno = Adafruit_BNO055(55);

#define BNO_SERVICE_UUID128     "36-9B-19-D1-A3-40-49-7E-A8-CE-DA-FA-92-D7-67-93"
#define BNO_YAW_CHAR_UUID128    "94-34-C1-6F-B0-11-45-90-8B-E3-2F-97-D6-3C-C5-49"
#define BNO_MOTOR_CHAR_UUID128  "14-EC-99-94-49-32-4B-DA-99-7A-B3-D0-52-CD-74-21"


// Create the bluefruit object, either software serial...uncomment these lines
/*
SoftwareSerial bluefruitSS = SoftwareSerial(BLUEFRUIT_SWUART_TXD_PIN, BLUEFRUIT_SWUART_RXD_PIN);
Adafruit_BluefruitLE_UART ble(bluefruitSS, BLUEFRUIT_UART_MODE_PIN,
                      BLUEFRUIT_UART_CTS_PIN, BLUEFRUIT_UART_RTS_PIN);
*/

/* ...or hardware serial, which does not need the RTS/CTS pins. Uncomment this line */
// Adafruit_BluefruitLE_UART ble(BLUEFRUIT_HWSERIAL_NAME, BLUEFRUIT_UART_MODE_PIN);

/* ...hardware SPI, using SCK/MOSI/MISO hardware SPI pins and then user selected CS/IRQ/RST */
Adafruit_BluefruitLE_SPI ble(BLUEFRUIT_SPI_CS, BLUEFRUIT_SPI_IRQ, BLUEFRUIT_SPI_RST);

// A small helper
void error(const __FlashStringHelper*err) {
  Serial.println(err);
  while (1);
}

/* The service information */

int32_t bnoServiceId;
int32_t bnoYawCharId;
int32_t bnoMotorCharId;
/**************************************************************************/
/*!
    @brief  Sets up the HW an the BLE module (this function is called
            automatically on startup)
*/
/**************************************************************************/
const int motorPin = 5;
const int ledPin = 9;
int current_guitar_string = 0;
int last_guitar_string = 0;
int led_flash_time = 2000;
int last_led_flash_time;
int led_on_time = 20;
bool switch_off_led = false;

void setCharValue(int32_t charId, float value, int precision=2){
  // Set the specified characteristic to a floating point value.
  // Construct an AT+GATTCHAR command to send the float value.
  // The command will look like: AT+GATTCHAR=<charId>,<value as array of bytes>
  ble.print(F("AT+GATTCHAR="));
  ble.print(charId, DEC);
  ble.print(F(","));
  ble.println(value, precision);
  
  if (!ble.waitForOK())
  {
    Serial.println(F("Failed to get response!"));
  }
}

void setup(void)
{
  pinMode(motorPin, OUTPUT);
  pinMode(ledPin, OUTPUT);
  digitalWrite(motorPin, LOW);
  analogWrite(ledPin, 5);
  
  // while (!Serial); // required for Flora & Micro
  delay(500);

  boolean success;

  Serial.begin(115200);

  randomSeed(micros());

  /* Initialise the module */
  Serial.print(F("Initialising the Bluefruit LE module: "));

  if ( !ble.begin(VERBOSE_MODE) )
  {
    error(F("Couldn't find Bluefruit, make sure it's in CoMmanD mode & check wiring?"));
  }
  Serial.println( F("OK!") );

  /* Perform a factory reset to make sure everything is in a known state */
  Serial.println(F("Performing a factory reset: "));
  if (! ble.factoryReset() ){
       error(F("Couldn't factory reset"));
  }

  /* Disable command echo from Bluefruit */
  ble.echo(false);

  Serial.println("Requesting Bluefruit info:");
  /* Print Bluefruit information */
  ble.info();

  // this line is particularly require for Flora, but is a good idea
  // anyways for the super long lines ahead!
  // ble.setInterCharWriteDelay(5); // 5 ms

  /* Change the device name to make it easier to find */
  Serial.println(F("Setting device name to 'BNO': "));

  if (! ble.sendCommandCheckOK(F("AT+GAPDEVNAME=BNO")) ) {
    error(F("Could not set device name?"));
  }

  /* Add the Heart Rate Service definition */
  /* Service ID should be 1 */
  Serial.println(F("Adding the BNO Service definition: "));
  success = ble.sendCommandWithIntReply( F("AT+GATTADDSERVICE=UUID128=" BNO_SERVICE_UUID128), &bnoServiceId);
  if (! success) {
    error(F("Could not add BNO service"));
  }

  /* Add the Heart Rate Measurement characteristic */
  /* Chars ID for Measurement should be 1 */
  Serial.println(F("Adding the BNO Yaw characteristic: "));
  success = ble.sendCommandWithIntReply( F("AT+GATTADDCHAR=UUID128=" BNO_YAW_CHAR_UUID128 ", PROPERTIES=0x12, MIN_LEN=2, MAX_LEN=3, VALUE=00=40"), &bnoYawCharId);
    if (! success) {
    error(F("Could not add BNO Yaw characteristic"));
  }

  /* Add the Body Sensor Location characteristic */
  /* Chars ID for Body should be 2 */
  Serial.println(F("Adding the BNO Motor characteristic: "));
  success = ble.sendCommandWithIntReply( F("AT+GATTADDCHAR=UUID128=" BNO_MOTOR_CHAR_UUID128 ", PROPERTIES=0x04, MIN_LEN=1, VALUE=20"), &bnoMotorCharId);
    if (! success) {
    error(F("Could not add BNO Motor characteristic"));
  }

  /* Reset the device for the new service setting changes to take effect */
  Serial.print(F("Performing a SW reset (service changes require a reset): "));
  ble.reset();

  Serial.println();

  /* Initialise the sensor */
  if(!bno.begin())
  {
    /* There was a problem detecting the BNO055 ... check your connections */
    Serial.print("Ooops, no BNO055 detected ... Check your wiring or I2C ADDR!");
    while(1);
  }
  
  delay(1000);
  
  bno.setExtCrystalUse(true);
  setCharValue(bnoMotorCharId, current_guitar_string);

  last_led_flash_time = millis();
}

void loop(void) 
{  
  /* Get a new sensor event */ 
  sensors_event_t event; 
  bno.getEvent(&event);
  
  // does the yaw position correspond to the position of any of the guitar strings?
  if (event.orientation.y <= -3 && event.orientation.y >= -8)
  {
    current_guitar_string = 5;
  } else if (event.orientation.y <= -13 && event.orientation.y >= -18)
  {
    current_guitar_string = 4;
  } else if (event.orientation.y <= -23 && event.orientation.y >= -28)
  {
    current_guitar_string = 3;
  } else if (event.orientation.y <= -33 && event.orientation.y >= -38)
  {
    current_guitar_string = 2;
  } else if (event.orientation.y <= -43 && event.orientation.y >= -48)
  {
    current_guitar_string = 1;
  } else if (event.orientation.y <= -53 && event.orientation.y >= -58)
  {
    current_guitar_string = 0;
  } else 
  {
    current_guitar_string = -1;
  }

  // has the guitar string changed?
  if (current_guitar_string != last_guitar_string)
  {
   // set the yaw characteristic value
    setCharValue(bnoYawCharId, current_guitar_string);
    // trigger the motor
    if (current_guitar_string != -1)
    {
      digitalWrite(motorPin, HIGH);
      delay(50);
      digitalWrite(motorPin, LOW);
    }
    last_guitar_string = current_guitar_string;
  }
}

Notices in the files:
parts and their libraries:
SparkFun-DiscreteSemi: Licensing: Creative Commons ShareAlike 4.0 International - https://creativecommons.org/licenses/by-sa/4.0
